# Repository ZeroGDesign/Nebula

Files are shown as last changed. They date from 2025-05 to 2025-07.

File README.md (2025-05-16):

# MercuryOne
The home of the ZeroG Nebula Project!

## License

This work is licensed under the [Creative Commons Attribution-NonCommercial-ShareAlike 4.0 International License](https://creativecommons.org/licenses/by-nc-sa/4.0/).



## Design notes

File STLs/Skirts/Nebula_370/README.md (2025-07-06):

# Nebula 370 Skirts

### Short Skirts

The short skirts are the same depth as the stock Ender 5 Plus frame, and are made to fit work benches and tables that are 600mm deep or around 23 inches. This is a common depth for many work benches.

### Full Skirts

The full skirts extend the full depth of the frame, and require at least 610mm or just over 24 inches in depth.

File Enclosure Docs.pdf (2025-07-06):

# A Zero G Enclosure

# NEBULA

# For The Mercury One.1 and Hydra

NEBULA 255 | NEBULA 370

Included in this manual is the step-by-step guide and BOM for the Nebula 255 and 370. Both frames are assembled in the same way, with hardware quantity and extrusion length differences.

## There are a few recommended tools that are required, and some additional items that are

recommended.

QTY | Part Description | QTY | Part Description
6 | 5x7x8mm Bushing | | 8 | M5x6 BHCS
3 | 5x50 pin | | 66 | M5x10 BHCS
36 | 6x3 Magnet | | 6 | M5x10 FHCS
16 | 10x3 Magnet | | 4 | M5x12 SHCS
2 | M3x8 FHCS | | 14 | M5x18 SHCS
36 | M3x8 BHCS | | 26 | M3 X D5.0 X L4.0 - Heat-set
38 | M3x8 SHCS | | 52 | M5 Roll In T-Nut
46 | M3x12 SHCS | | 1 | 3x5mm Foam Tape | 10 Meters
8 | M3x14 SHCS | | 4 | M5 Hex Nut
106 | M3 Roll In T-nut | | 4 | 38x19mm Rubber Foot

# NEBULA 255 HARDWARE BOM

QTY | Part Description | QTY | Part Description
12 | 5x7x8mm Bushing | | 8 | M5x6 BHCS
6 | 5x50 pin | | 66 | M5x10 BHCS
36 | 6x3 Magnet | | 6 | M5x10 FHCS
48 | 10x3 Magnet | | 4 | M5x12 SHCS
2 | M3x8 FHCS | | 14 | M5x18 SHCS
44 | M3x8 BHCS | | 34 | M3 X D5.0 X L4.0 - Heat-set
46 | M3x8 SHCS | | 52 | M5 Roll In T-Nut
52 | M3x12 SHCS | | 1 | 3x5mm Foam Tape | 15 Meters
8 | M3x14 SHCS | | 4 | M5 Hex Nut
118 | M3 Roll In T-nut | | 4 | 38x19mm Rubber Foot

# NEBULA 370 HARDWARE BOM

# EXTRUSION BOM

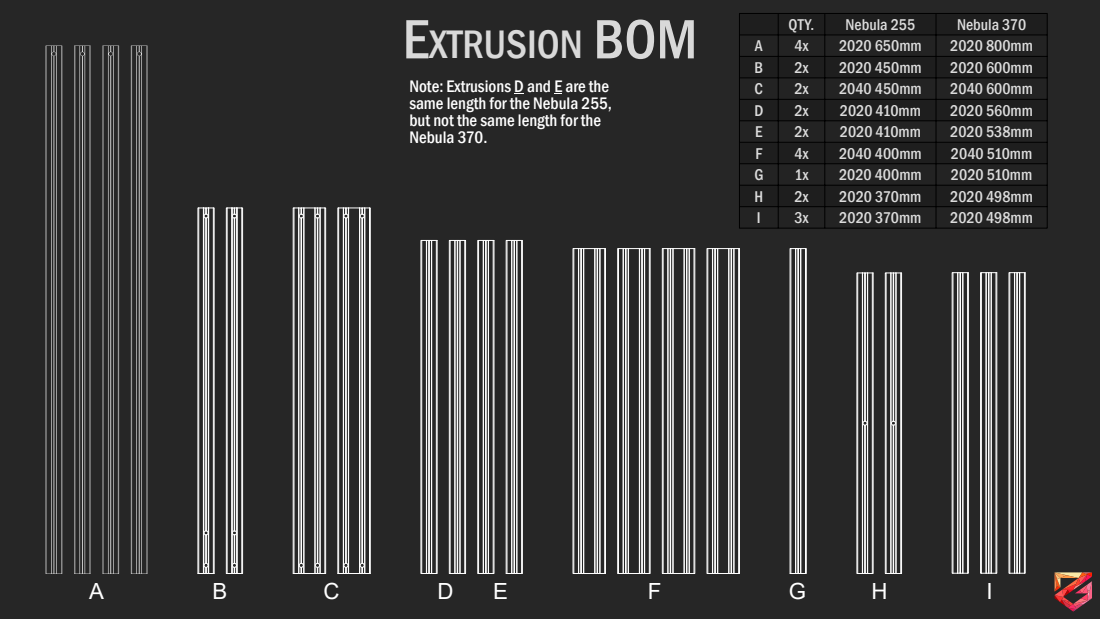
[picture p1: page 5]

QTY. | Nebula 255 | Nebula 370
A | 4x | 2020 650mm | 2020 800mm
B | 2x | 2020 450mm | 2020 600mm
C | 2x | 2040 450mm | 2040 600mm
D | 2x | 2020 410mm | 2020 560mm
E | 2x | 2020 410mm | 2020 538mm
F | 4x | 2040 400mm | 2040 510mm
G | 1x | 2020 400mm | 2020 510mm
H | 2x | 2020 370mm | 2020 498mm
I | 3x | 2020 370mm | 2020 498mm

Note: Extrusions D and E are the
same length for the Nebula 255,
but not the same length for the
Nebula 370.

## -Place the 2020 upright next to the 2040 upright to position the 2

M5 T-nuts and 2 M5x6 BHCS. -Do this for all 4 uprights.

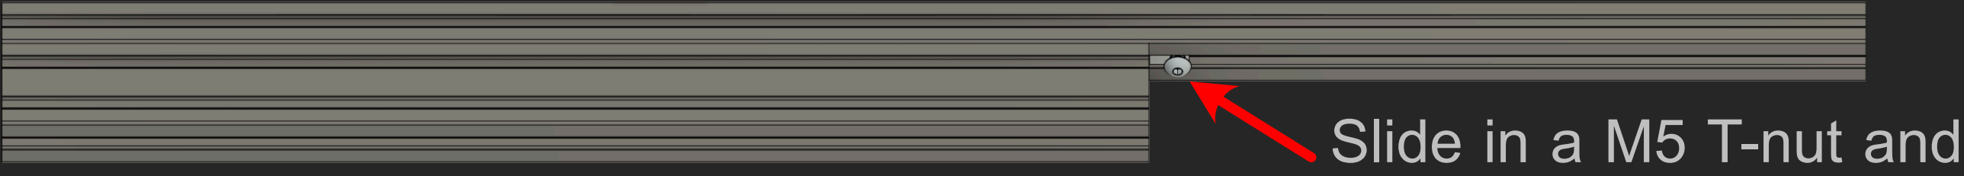
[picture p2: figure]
Slide in a M5 T-nut and

## M5x6 BHCS. This is for the Y Gantry extrusion

# ASSEMBLING THE UPRIGHTS

| QTY. | Nebula 255 | Nebula 370
A | 4x | 2020 650mm | 2020 800mm
G | 4x | 2020 400mm | 2020 510mm
| 10x | M5 T-Nut | M5 T-Nut
| 10x | M5x6 BHCS | M5x6 BHCS

# ASSEMBLING THE FRONT SECTION

E

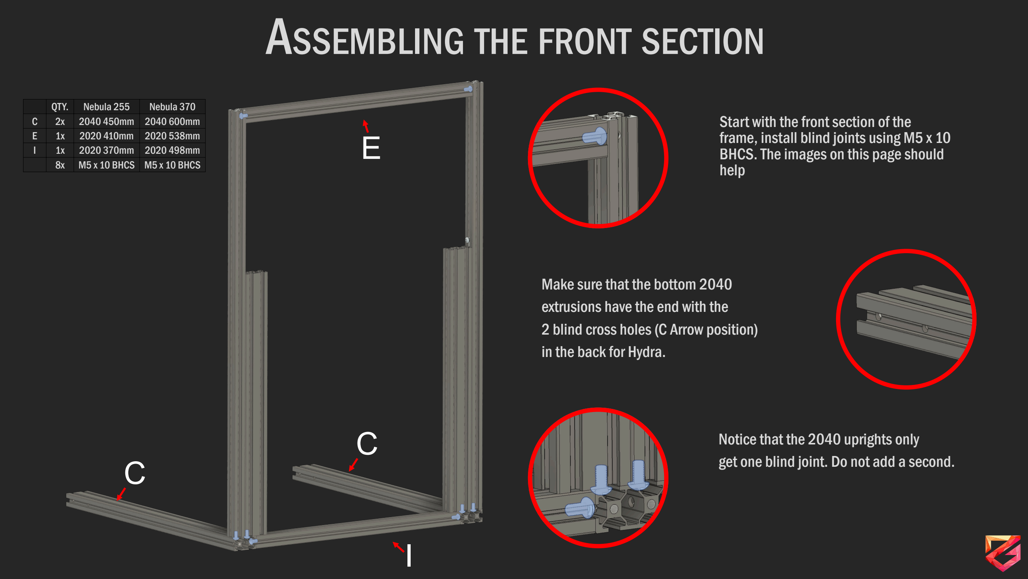
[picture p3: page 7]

Start with the front section of the frame, install blind joints using M5 x 10 BHCS. The images on this page should help

Make sure that the bottom 2040 extrusions have the end with the
2 blind cross holes (C Arrow position) in the back for Hydra.

Notice that the 2040 uprights only
get one blind joint. Do not add a second.
| QTY. | Nebula 255 | Nebula 370
C | 2x | 2040 450mm | 2040 600mm
E | 1x | 2020 410mm | 2020 538mm
I | 1x | 2020 370mm | 2020 498mm
| 8x | M5 x 10 BHCS | M5 x 10 BHCS

C

C

I

# INSTALL THE REAR UPRIGHTS

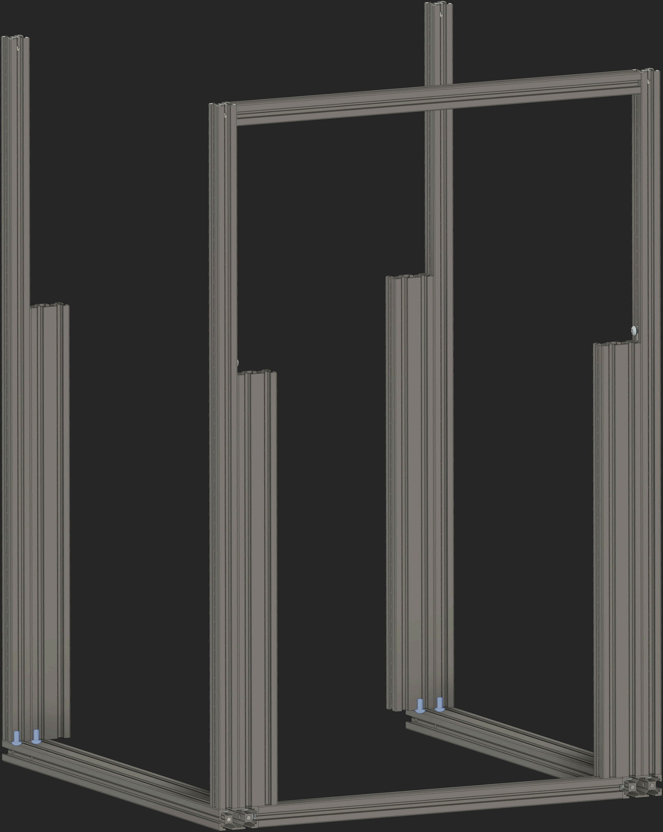
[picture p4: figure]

Now you can install the rear 2 uprights. We will add more support in the next step.

*NOTE* It is helpful to lay the frame on its side to help tighten the blind joints.

QTY. | Nebula 255 | Nebula 370
4x | M5 x 10 BHCS | M5 x 10 BHCS

# INSTALL THE TOP BRACES

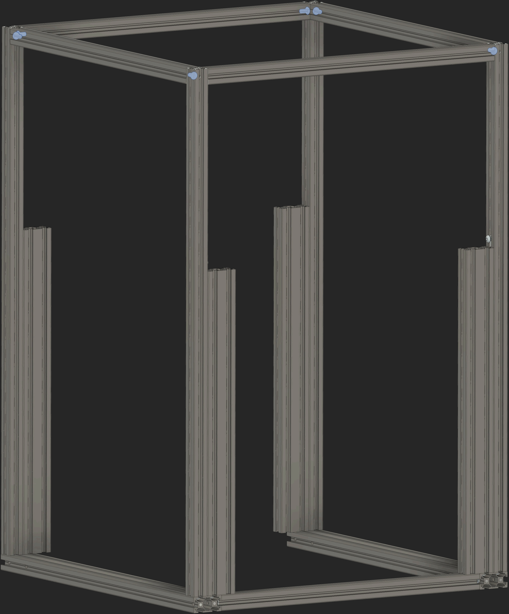
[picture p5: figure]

Add the remaining 3 top extrusions now using M5 x 10 BHCS.

| QTY. | Nebula 255 | Nebula 370
D | 2x | 2020 410mm | 2020 560mm
E | 1x | 2020 410mm | 2020 538mm
| 6x | M5 x 10 BHCS | M5 x 10 BHCS

# INSTALLING Y GANTRY BARS

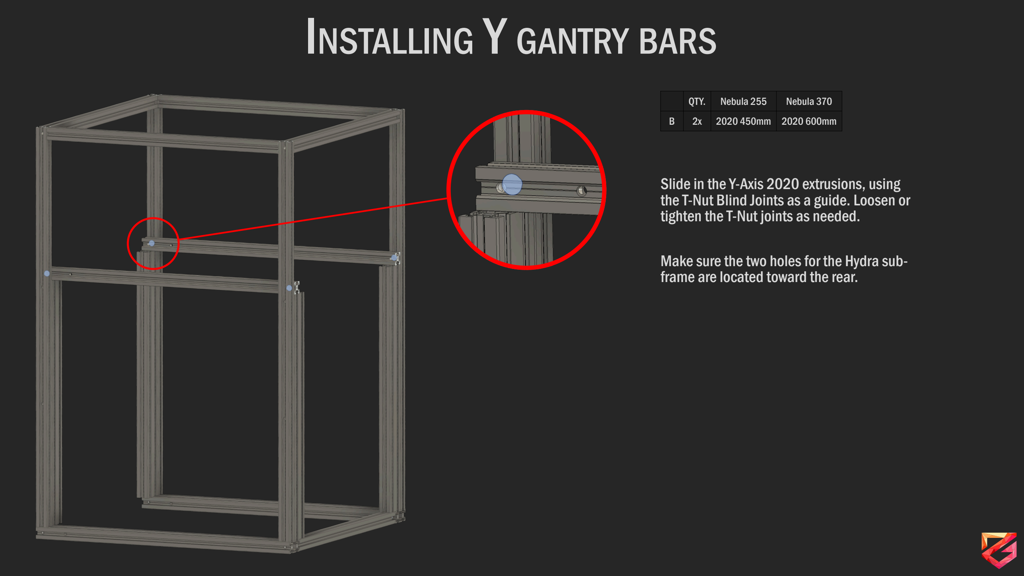
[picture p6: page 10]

Slide in the Y-Axis 2020 extrusions, using the T-Nut Blind Joints as a guide. Loosen or tighten the T-Nut joints as needed.

Make sure the two holes for the Hydra sub-frame are located toward the rear.

| QTY. | Nebula 255 | Nebula 370
B | 2x | 2020 450mm | 2020 600mm

# ASSEMBLE REAR HYDRA UPRIGHT SUB-FRAME

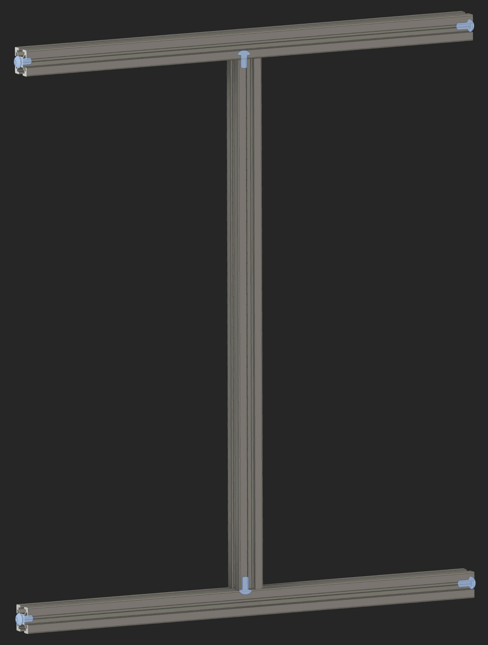
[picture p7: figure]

Prepare the Hydra sub-frame as shown.

| QTY. | Nebula 255 | Nebula 370
G | 1x | 2020 400mm | 2020 510mm
H | 2x | 2020 370mm | 2020 498mm
| 6x | M5 x 10 BHCS | M5 x 10 BHCS

# INSERT HYDRA SUB-FRAME

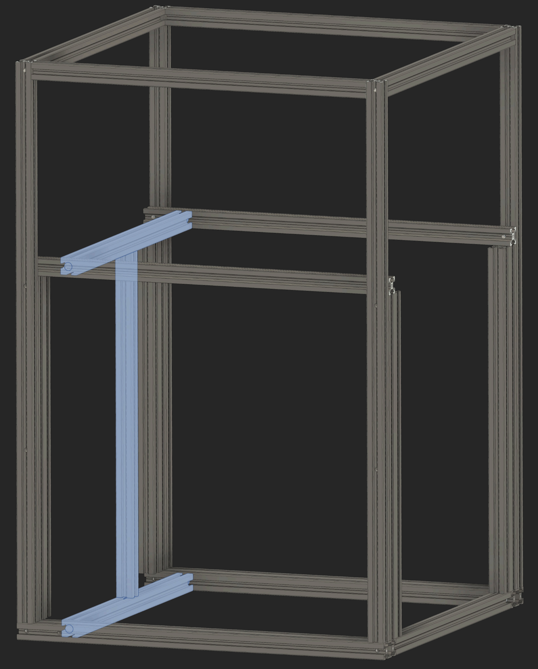
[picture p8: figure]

Slide in the Hydra sub frame, placing it 40mm from the back edge of the frame for the 255 frame, or 45mm for the 370 frame.

# INSTALL FINAL REAR BOTTOM BRACE

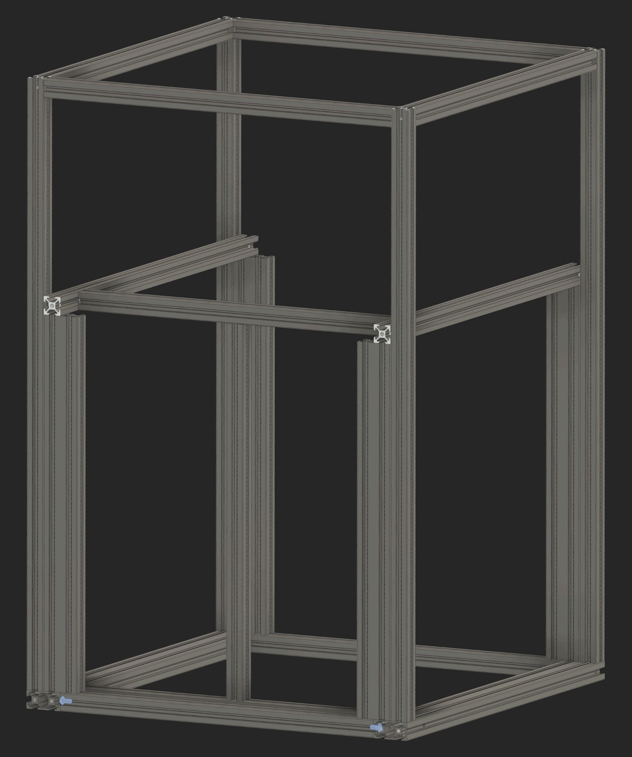
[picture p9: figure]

Install the final rear 2020 extrusion.

Then spend some time squaring up the frame the best you can.

| QTY. | Nebula 255 | Nebula 370
I | 3x | 2020 370mm | 2020 498m
| 2x | M5 x 10 BHCS | M5 x 10 BHCS

# NEBULA 370 DOOR PANELS

# NEBULA 255 DOOR PANEL

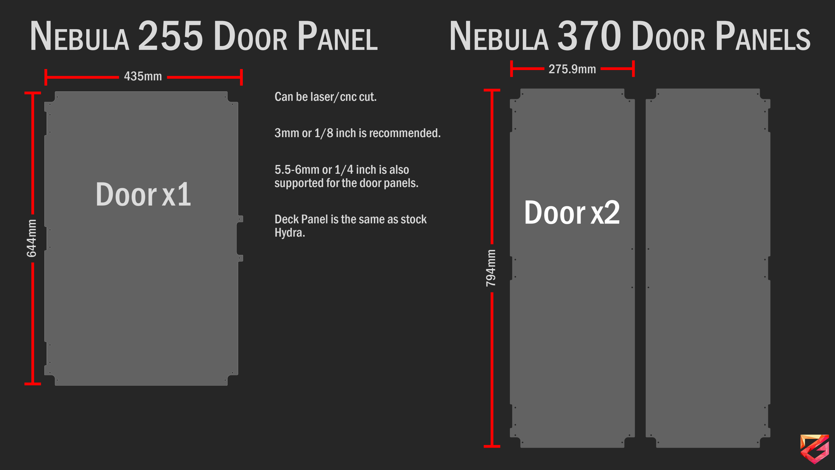
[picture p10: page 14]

Can be laser/cnc cut.

3mm or 1/8 inch is recommended.

5.5-6mm or 1/4 inch is also supported for the door panels.

Deck Panel is the same as stock Hydra.

435mm

644mm

794mm

275.9mm

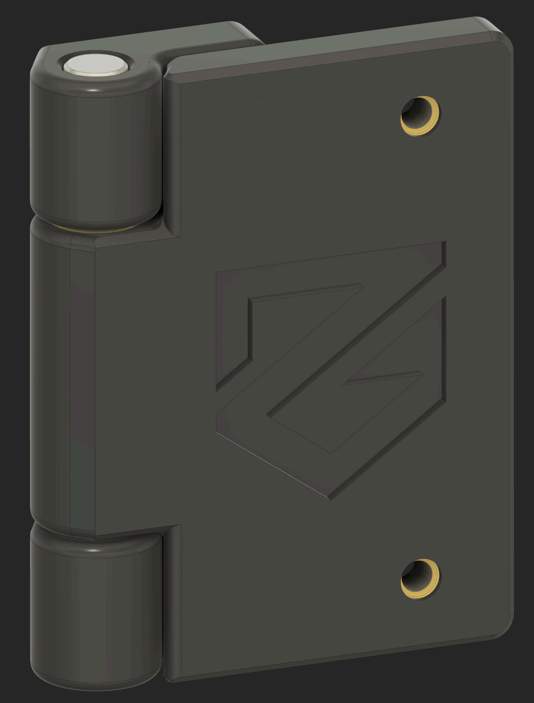
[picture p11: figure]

## BOM per door hinge assembly *Note* for Hinges, there is a ZeroG Logo option

# DOOR HINGES

QTY. | Nebula 255 | QTY. | Nebula 370
3x | Printed Base Hinge | 6x | Printed Base Hinge
3x | Printed Hinge | 6x | Printed Hinge
6x | 5x7x8 Bronze Bushing | 12x | 5x7x8 Bronze Bushing
3x | 5x50 Dowel Pin | 6x | 5x50 Dowel Pin
6x | M3x5x4 Heat-set Insert | 12x | M3x5x4 Heat-set Insert
6x | M3 x 8 BHCS | 12x | M3 x 8 BHCS

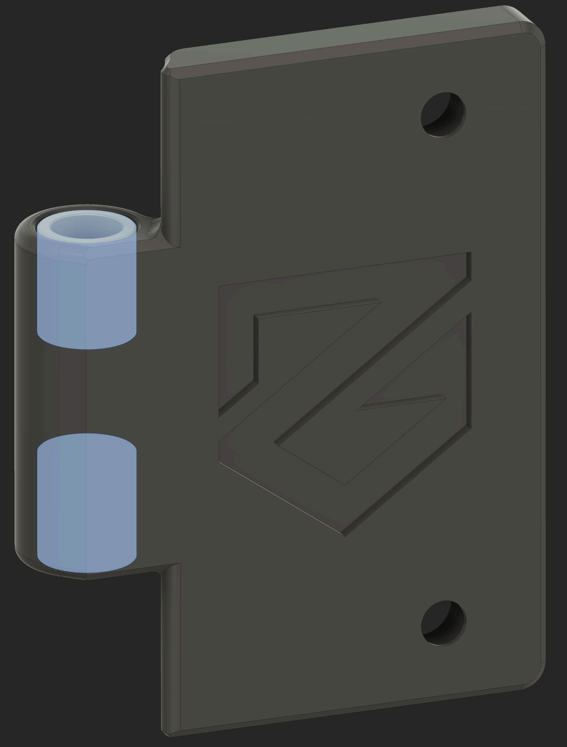
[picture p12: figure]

## Check that the bushings slide freely along the shaft. If they do not, you will need to sand the

shaft.

Press the bushings in,

## they should be a light press fit with your fingers. If they require more force, you should adjust your print settings and reprint them or ream

out the holes.

# PIN AND BUSHINGS

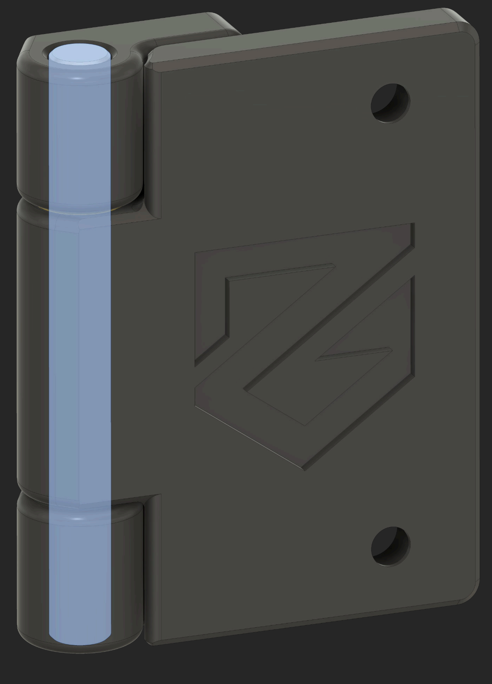
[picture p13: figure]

## Insert the 5x50mm dowel pin that you test fit with the bushings to

complete the main assembly.

# MAIN ASSEMBLY

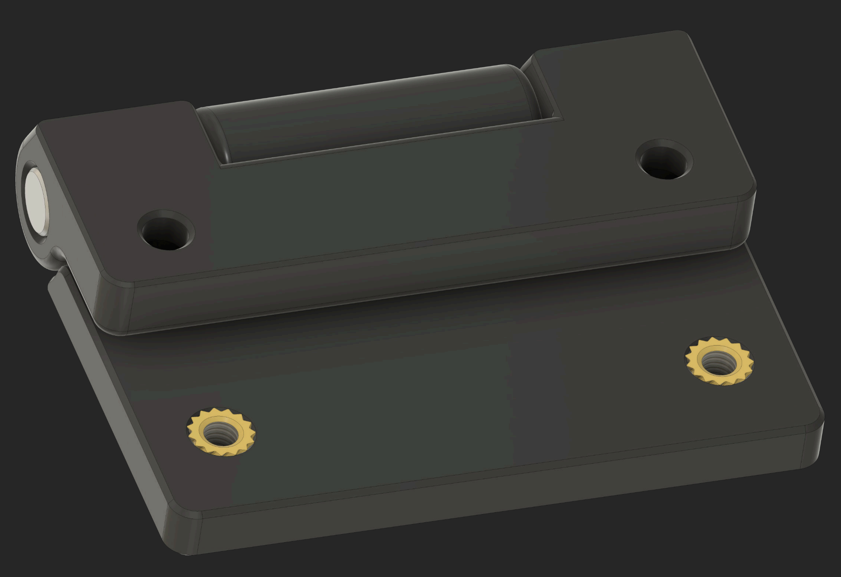
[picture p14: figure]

## Insert 2 M3 heat-set's

# INSERT HEAT-SETS

# BOTTOM 2040 DOOR CATCH

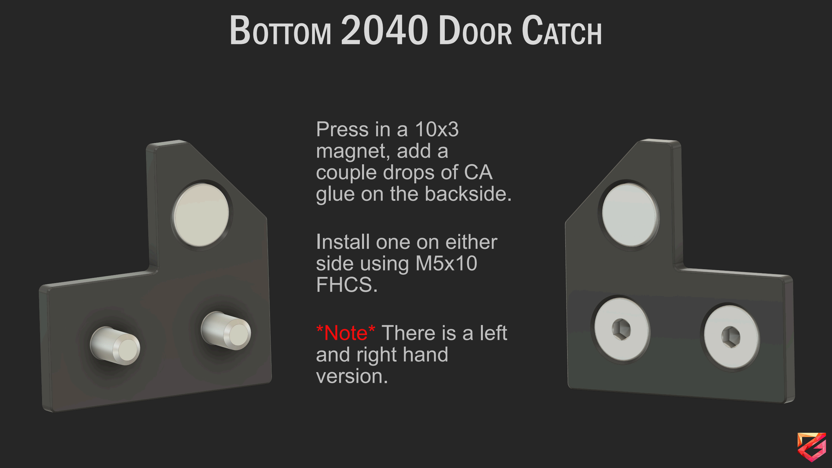
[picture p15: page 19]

## Press in a 10x3 magnet, add a couple drops of CA

glue on the backside.

## Install one on either side using M5x10

FHCS.

## *Note* There is a left and right hand

version.

# UPPER FRAME DOOR CATCH

Press in 3 10x2 magnets,

## you can add some CA glue in the pocket before

installing the magnet.

## Install into both upper inside corners of the frame with the magnet facing forward using M3 T-nuts and M3x8 SHCS

# DOOR CORNER CAPS

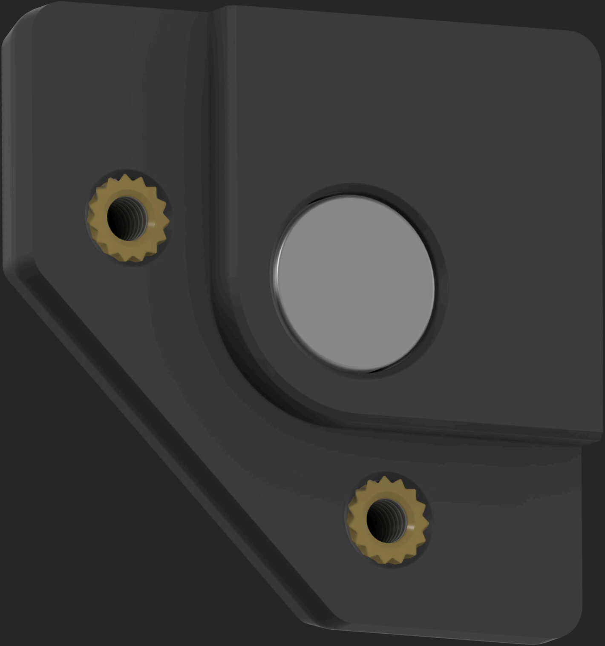
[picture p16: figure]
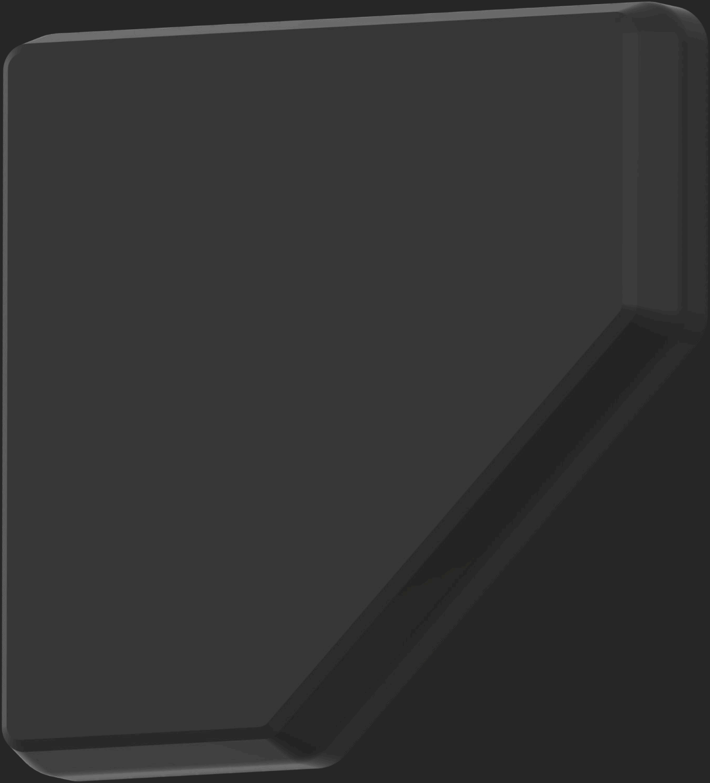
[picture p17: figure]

## Press fit 2 10x2 magnets into the pocket. Install heatsets in the other

holes.

## Install one in each corner using M3x8 BHCS

# 255 MAGNETIC DOOR CATCH

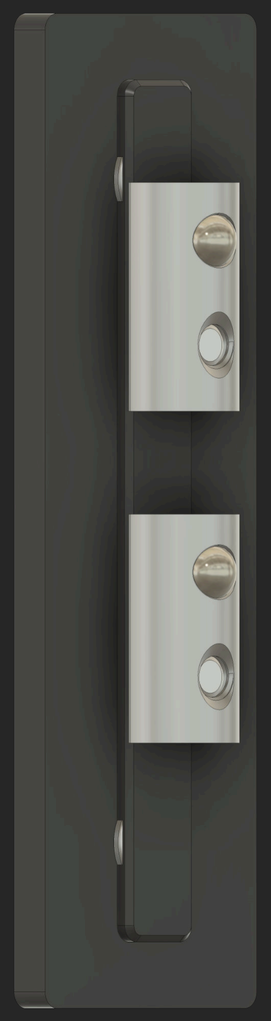
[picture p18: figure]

Apply some CA glue into each magnet pocket, then press fit the 6x3mm magnets.
Install onto the 2020 upright using M3x8 FHCS and M3 T-nuts.

# 255 DOOR HANDLE

Install 4 M3 heat-set inserts into the main handle. Attach the spacer to the handle using 2 M3x8 FHCS. Glue 2 6x3 magnets into each pocket. Then install onto the door using M3x8 BHCS

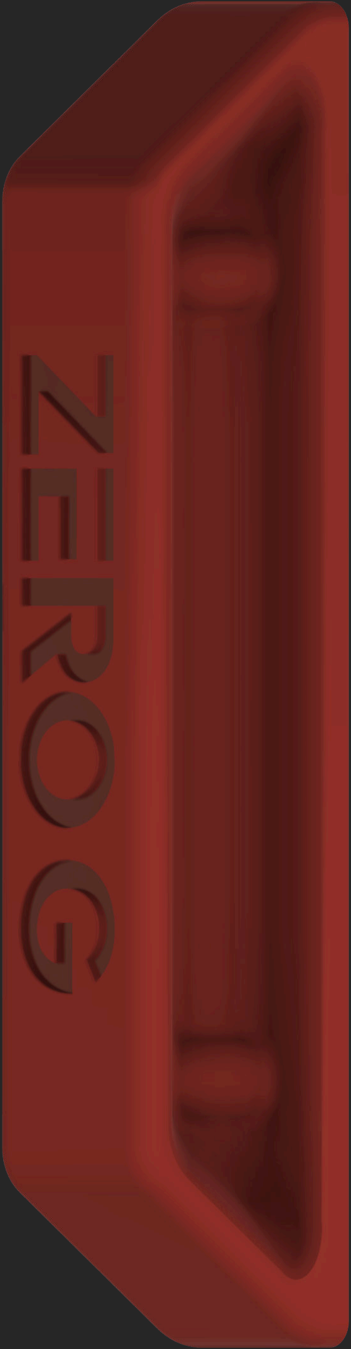
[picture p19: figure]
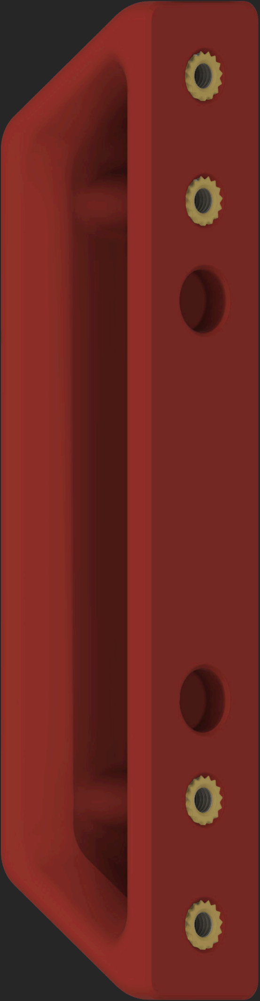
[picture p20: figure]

# 370 DOOR HANDLE

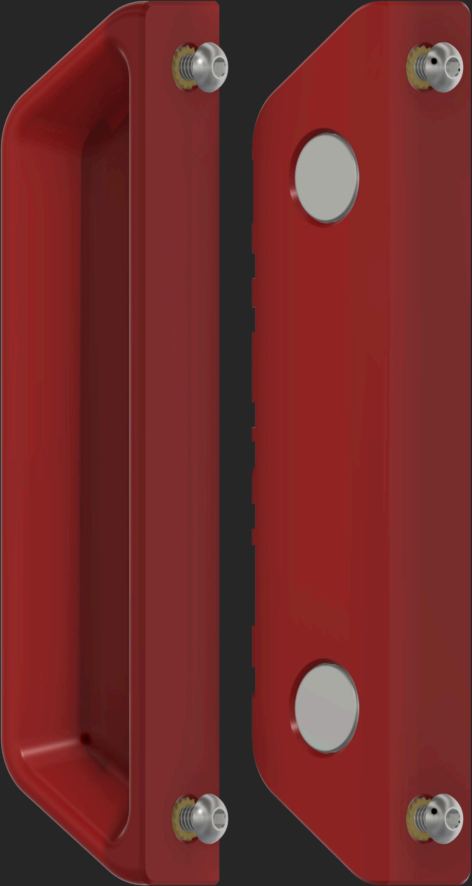
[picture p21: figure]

Install two M3 heat-set inserts into each handle, then press in two 10x2mm magnets into each each magnet pocket. Attach to the door using M3x8 BHCS.

# NEBULA 255 SIDE AND TOP PANELS

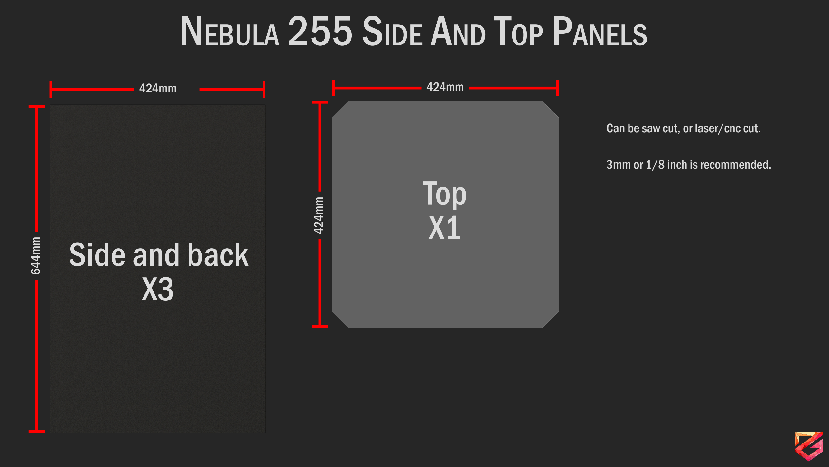
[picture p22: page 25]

424mm

644mm

Can be saw cut, or laser/cnc cut.

3mm or 1/8 inch is recommended.

424mm

424mm

# Side and back

X3

# Top

X1

# NEBULA 255 ELECTRONICS BAY PANELS

## Laser or CNC cut

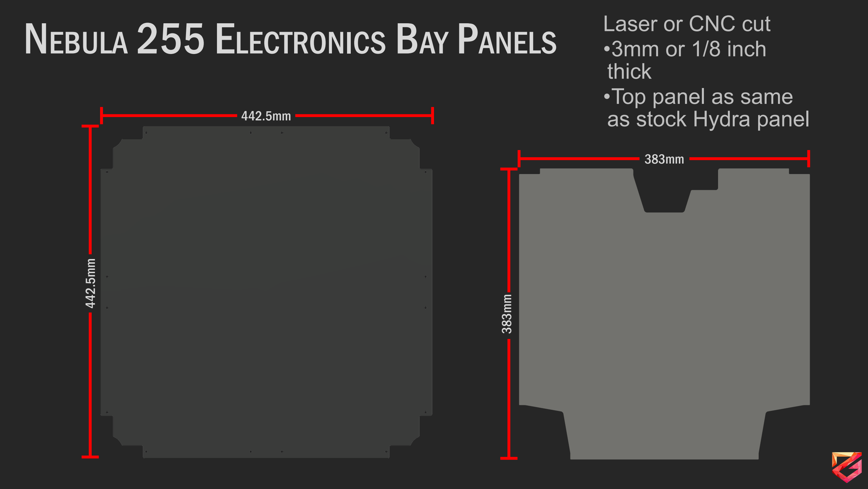
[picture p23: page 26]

442.5mm

442.5mm

383mm

383mm

## - 3mm or 1/8 inch thick - Top panel as same as stock Hydra panel

# NEBULA 370 SIDE, BACK, AND TOP PANELS

574mm

792mm

Can be saw cut, or laser/cnc cut.

3mm or 1/8 inch is recommended.

542mm

# Side Panel X2

574mm

552mm

792mm

Back Panel X1 | Top Panel X1

# NEBULA 370 ELECTRONICS BAY PANELS

## Laser or CNC cut

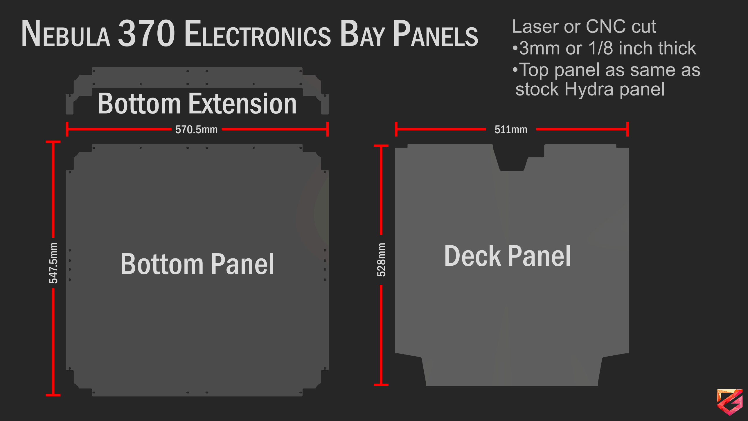
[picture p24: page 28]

570.5mm | 511mm

547.5mm
528mm

## - 3mm or 1/8 inch thick - Top panel as same as stock Hydra panel

Bottom Panel | Deck Panel

# Bottom Extension

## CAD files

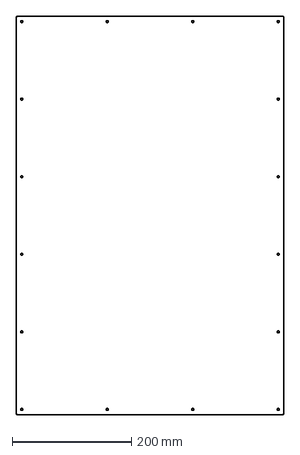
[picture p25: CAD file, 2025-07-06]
DFXs/255_DXF_Panels/Optional-Nebula_255_ACM_Panel_x3.dxf
448.0 x 668.0 mm

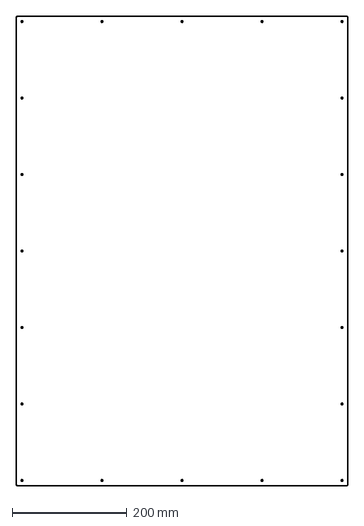
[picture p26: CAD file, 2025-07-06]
DFXs/370_DXF_Panels/Optional-Nebula_370_ACM_Rear_Panel.dxf
577.5 x 819.5 mm

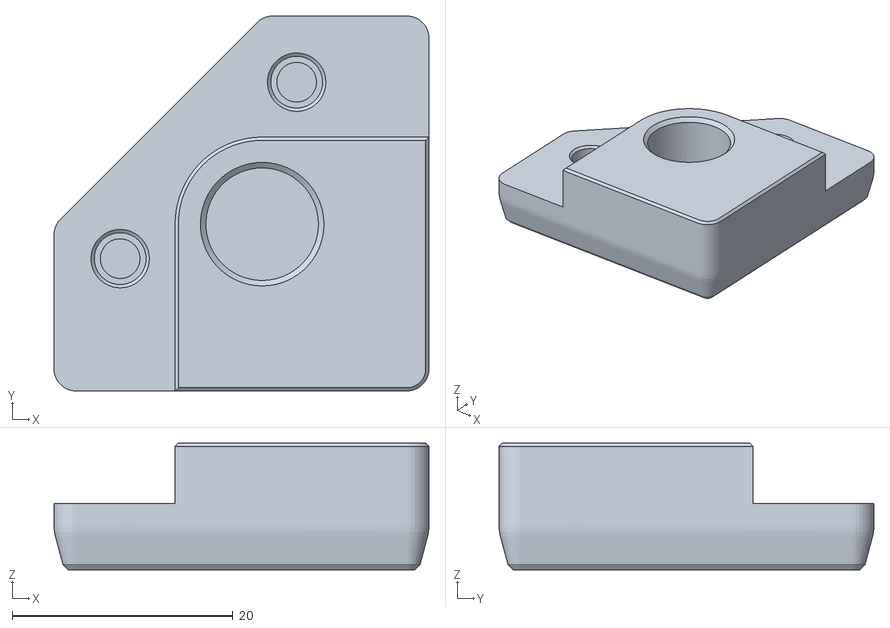
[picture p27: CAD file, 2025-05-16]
STLs/Doors/5_5mm_Thick_Front_ Doors/Magnet_Corner_Cap_5-5mm.stl
34.0 x 34.0 x 11.5

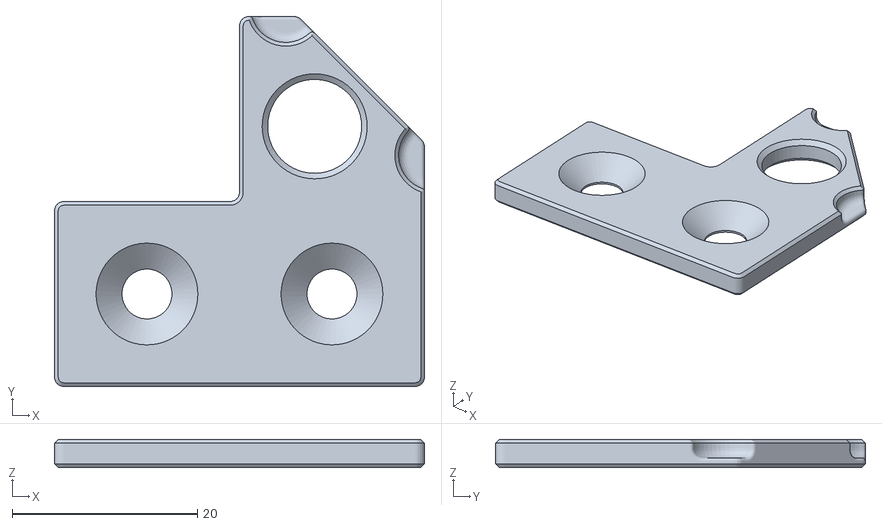
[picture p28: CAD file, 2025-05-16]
STLs/Doors/Magnet_2040_Mount_Left.stl
40.0 x 40.0 x 3.05

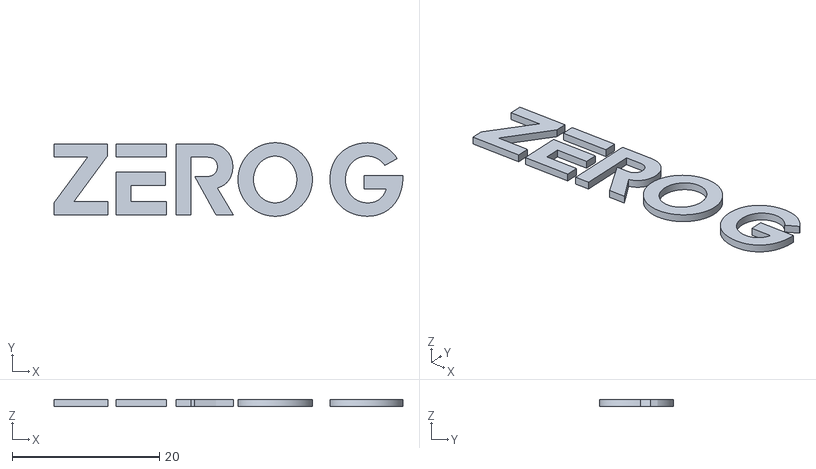
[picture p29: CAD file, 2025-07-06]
STLs/Doors/Nebula_255/Zerog_Handle_text.stl
47.4 x 10.00 x 1.00

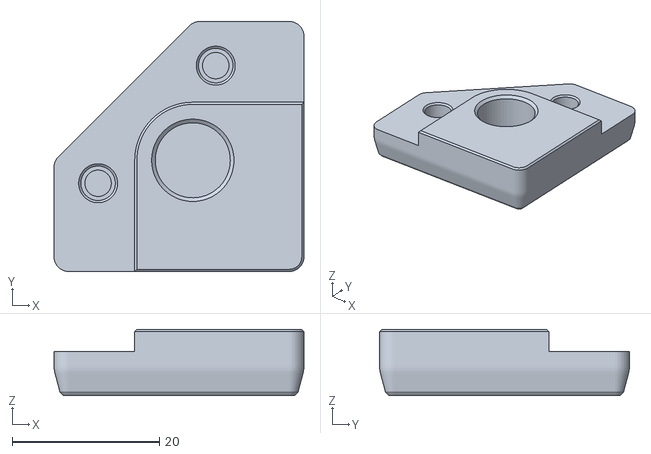
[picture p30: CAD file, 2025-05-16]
STLs/Doors/Nebula_370/Magnet_Corner_Cap_3mm_x8.stl
34.0 x 34.0 x 9.00

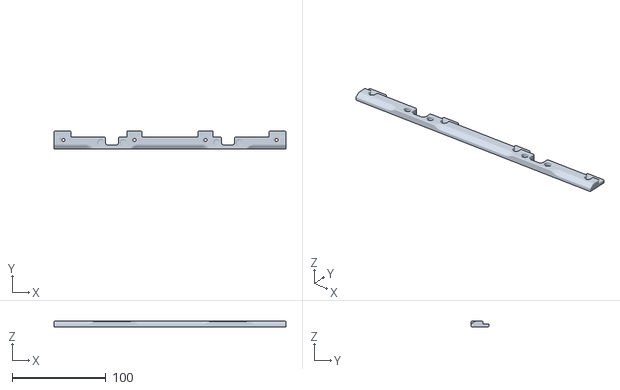
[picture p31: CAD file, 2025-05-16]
STLs/Electronics_Cover/Nebula_255/Filler_Panel_Front.stl
248.0 x 19.0 x 6.00

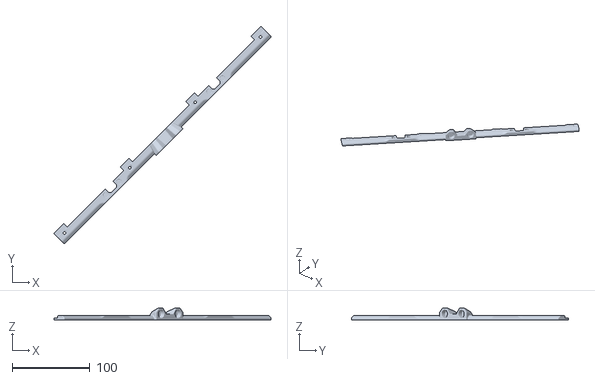
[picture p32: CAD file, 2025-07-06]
STLs/Electronics_Cover/Nebula_370/Filler_Panel_Front.stl
278.7 x 278.7 x 16.0

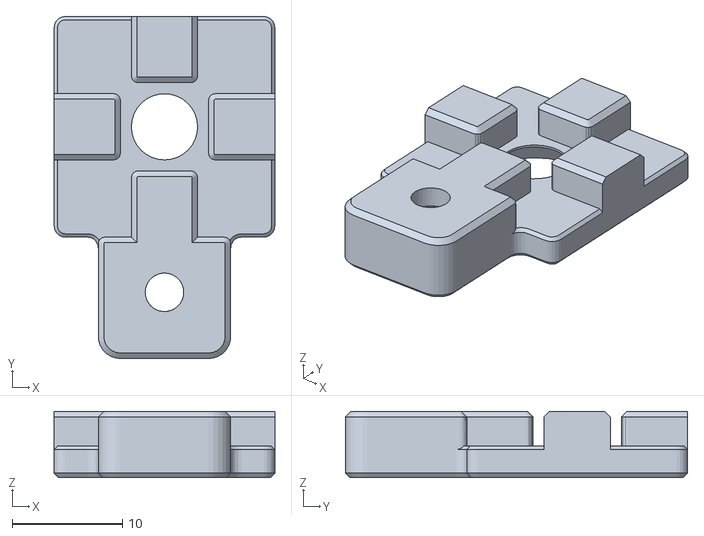
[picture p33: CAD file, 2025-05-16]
STLs/Misc/Enclosure_Tension_Plate.stl
20.0 x 31.0 x 6.00

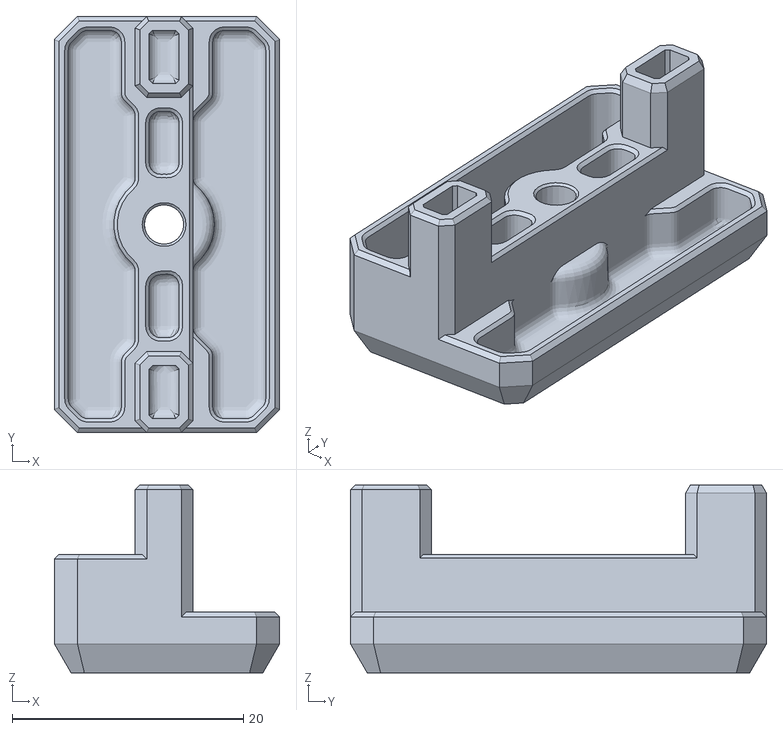
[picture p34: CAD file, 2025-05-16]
STLs/Optional_5mm_slot_with_files/Panel_Clip_Hollow_-_5mm.stl
19.5 x 36.0 x 16.2

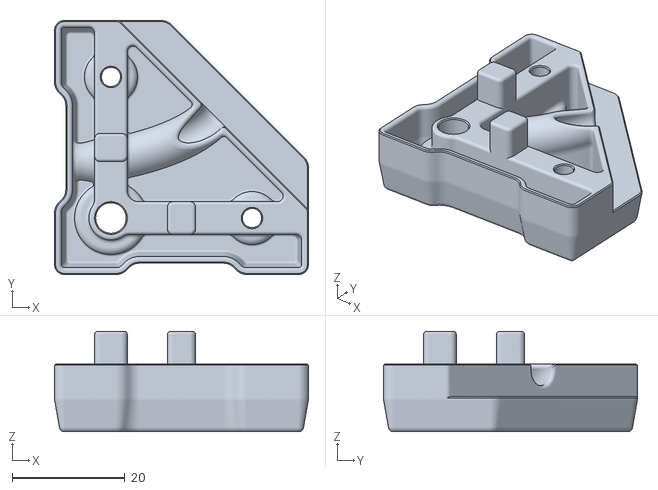
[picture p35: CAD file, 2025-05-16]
STLs/Panels/Top_Panel_Corner_Clip_FIlament_Entry.stl
45.0 x 45.0 x 17.8

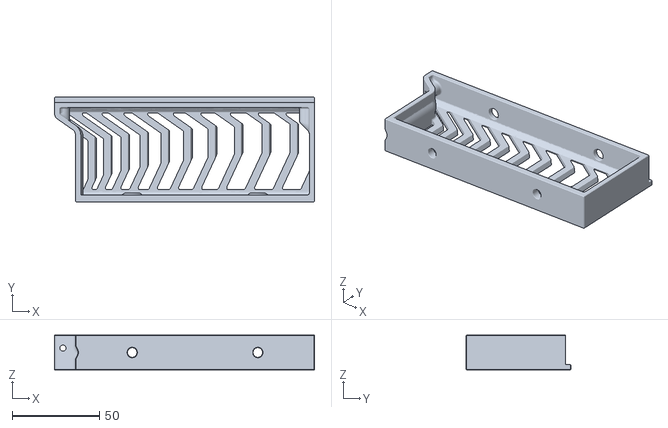
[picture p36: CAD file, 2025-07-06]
STLs/Skirts/Nebula_255/SK_330_Front_Right_V0-0-4.stl
149.1 x 60.0 x 20.0

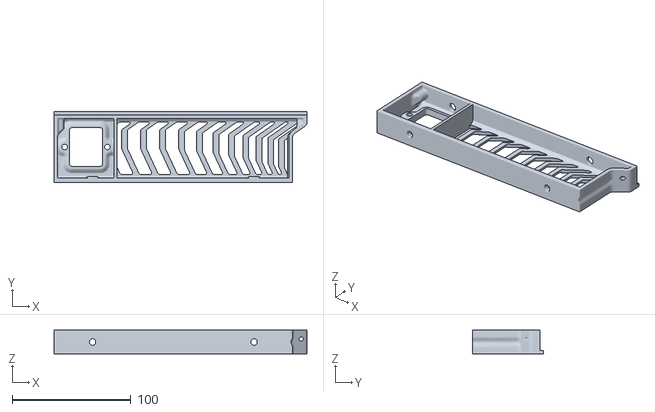
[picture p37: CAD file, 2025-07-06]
STLs/Skirts/Nebula_370/Full Skirt/SK-458-L_IEC_x1.stl
213.1 x 60.0 x 20.0

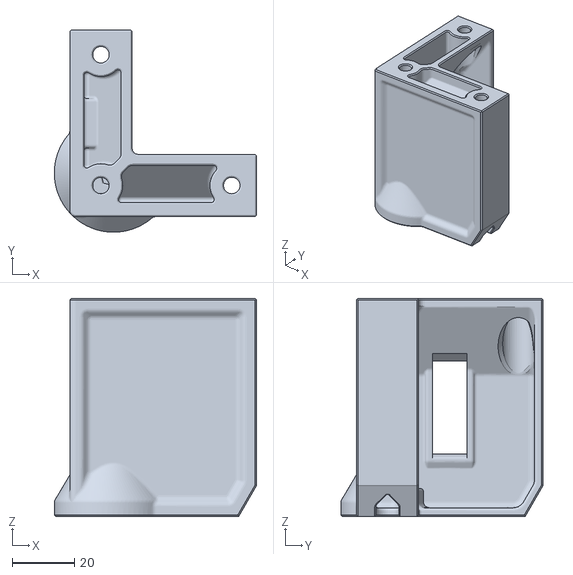
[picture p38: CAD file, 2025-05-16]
STLs/Skirts/Nebula_370/Short Skirt/SK_60mmFT_PowerSW_V1-02.stl
65.0 x 65.0 x 70.0

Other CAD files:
DFXs/255_DXF_Panels/Nebula_255_Top_Panel.dxf
DFXs/370_DXF_Panels/Optional-Nebula_370_ACM_Side_Panel_x2.dxf
STLs/Doors/5_5mm_Thick_Front_ Doors/Base_Hinge_5-5mm.stl
STLs/Doors/Magnet_2040_Mount_Right.stl
DFXs/255_DXF_Panels/Nebula_255_Bottom_Panel.dxf
DFXs/255_DXF_Panels/Nebula_255_Deck_Panel.dxf
DFXs/255_DXF_Panels/Nebula_255_Front_Door.dxf
DFXs/255_DXF_Panels/Nebula_255_Side_Panel_x3.dxf
DFXs/370_DXF_Panels/Nebula_370_Back_Panel.dxf
DFXs/370_DXF_Panels/Nebula_370_Bottom_Extension.dxf
DFXs/370_DXF_Panels/Nebula_370_Bottom_Panel.dxf
DFXs/370_DXF_Panels/Nebula_370_Deck_Panel.dxf
DFXs/370_DXF_Panels/Nebula_370_Side_Panel_x2.dxf
DFXs/370_DXF_Panels/Nebula_370_Split_Door_x2.dxf
DFXs/370_DXF_Panels/Nebula_370_Top_Panel.dxf
STLs/Doors/5_5mm_Thick_Front_ Doors/Door_Handle_Spacer_5-5mm.stl
STLs/Doors/Magnet_Inside_Frame_Mount_x2.stl
STLs/Doors/Nebula_255/Base_Hinge_X3.stl
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

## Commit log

2025-05-16 Initial Upload Nebula
    [5_Plus_E_Rear_Skirt_Wing_L.stl, 5_Plus_E_Rear_Skirt_Wing_R.stl, Back_Filler_Left.stl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]
2025-07-06 File Updates and Assembly Guide
    Fixed some file naming issues, print orientations, and added the assembly guide for the frame.
    [Filler_Panel_Front.stl, Nebula_370_Extension_Brace_x2.stl, Optional-Nebula_255_ACM_Panel_x3.dxf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]
2026-10-28 Added CAD files and fixed a DXF
    Added Step files, frame drawings, and fixed the 255 bottom panel.
